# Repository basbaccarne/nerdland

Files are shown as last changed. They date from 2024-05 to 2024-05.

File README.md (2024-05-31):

#  ~~Nerdland~~  Nerdlamp
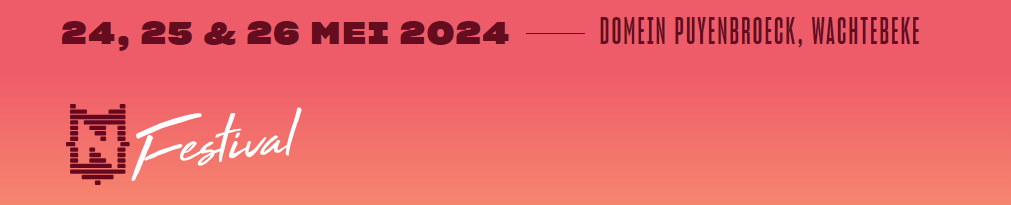
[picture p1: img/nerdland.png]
nerdland

*Made with* ❤ *by Lore Brosens, Bas Baccarne, Yannick Christiaens & Simon De Boever*   

This repo covers the set-up of the [UGent Campus Kortrijk](https://www.ugent.be/campus-kortrijk/) [Nerdland](https://www.nerdlandfestival.be/) installation. This introduces nerds into 4 domains:
- [**Interaction Design**](#interaction-design):   
Visitors can create their own paramertric design with an Arduino-controlled input device
- [**Computational Design**](#computational-design):   
This device feeds a firefly + grasshopper script that generates patterns in a predefined format
- [**Advanced Manufacturing**](#advanced-manufacturing):   
These shapes are exported as dxf files and laser cutted
- [**Design for Assembly**](#design-for-assembly):   
These personalised fragments can be assembled into a night lamp

These domains illustrate some of the key components of the [Ghent University](https://www.ugent.be/) programs [Machine & Production Automation](https://www.ugent.be/campus-kortrijk/nl/opleidingen/mpa) and [Industrial Design Engineering](https://www.ugent.be/campus-kortrijk/nl/opleidingen/industrieel-ontwerpen)

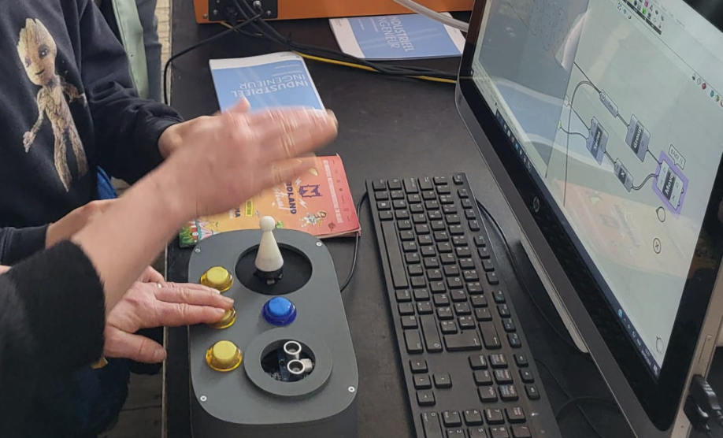
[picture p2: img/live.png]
live


## Interaction Design
### Components
- [Arduino Nano](https://store.arduino.cc/products/arduino-nano)
- [Grove Shield for Arduino Nano](https://wiki.seeedstudio.com/Grove_Shield_for_Arduino_Nano/)
- [Grove Thumbstick](https://wiki.seeedstudio.com/Grove-Thumb_Joystick/)
- [Grove Gesture Sensor 1.0](https://wiki.seeedstudio.com/Grove-Gesture_v1.0/)
- [Grove UltraSonic Ranger](https://wiki.seeedstudio.com/Grove-Ultrasonic_Ranger/)
- [4 arcade buttons](https://www.gotron.be/componenten/schakelmateriaal/schakelaars-en-drukknoppen/arcade-knoppen/lichtgevende-arcade-drukknop-30mm-groen.html)
- [Mini USB Cable](https://www.allekabels.be/usb-mini-kabel/176/4207900/mini-usb-kabel.html?lang=nl-be)
- [Case](https://a360.co/4drFMZX)
- [Joystick](https://a360.co/3WSIDWa)
### Set-up
- Connect the thumbstick to A0
- Connect the gesture sensor to I2C
- Connect the distance sensor to D2
- Connect button 1 to D5
- Connect button 2 to D7
- Connect button 3 to A3
- Connect button 4 to A2 
- Upload the [Arduino code](nerdland.ino)
### Input
- The interface changes the ```thumb stick``` values when the ```first button``` is pressed
- The interface changes the ```gestures``` when the ```second button``` is pressed
- The interfaces changes the ```distance``` when the ```third button``` is pressed
- The interface ```resets``` the values when the ```blue (fourth) button``` is pressed
### Output
- The arduino writes the data to the Serial Port in the folowing format   
  ```x_axis_thumb|y_axis_thumb|x_axis_gesture|y_axis_gesture|distance```

  ![console](img/console.jpg)
      
## Computational Design
- This Serial Data is read by [Firefly](https://www.food4rhino.com/en/app/firefly) and translated into computaional commands in [Grasshopper](https://www.grasshopper3d.com/)
- [This Grasshopper script](grasshopper.gh) shows how the data is processed in Grasshopper
- Parameters: ```size```, ```orientation```, ```pattern```, ```count``` & ```shape```
- The results are 5 copies of personalized segment designs
  
![grasshopper](img/grasshopper.png)   

## Advanced Manufacturing
- The Grasshopper result is baked and exported to a .dxf file
- The dxf file is printed on a laser cutter using [lightburn](https://lightburnsoftware.com/)
- Material: [Akyplen® wit 460 g/m²](https://igepa.nl/06-0007-0007-akyplenr-wit-460-g-m-700-mm-x-1000-mm-500)
- If you want to use the pregenerated design: this is the [file with the base segments](samples/Basis_File_10_sides_en_bodem.dxf) & this is a [pregenerated file with the parts with a pattern](samples/Accent_file_5_sides.dxf)
  
**Curious about the math behind this lamp?**
- The general shape is a [Rhombic triacontahedron](https://en.wikipedia.org/wiki/Rhombic_triacontahedron), with 30 rhombic (diamond-shaped) faces
- From this shape, we remove 20 faces in the middle
- See the video below for a basic visualization
  
https://github.com/basbaccarne/nerdland/assets/7208557/56421a35-1992-435b-bc12-0767cc13a605

## Design for Assembly
- The five segments are printed in the laser cutter
- Visitors get a enveloppe with
  - a preprinted [bottom part](samples/Basis_File_10_sides_en_bodem.dxf)
  - 10 preprinted [segments without a pattern](samples/Basis_File_10_sides_en_bodem.dxf)
  - a small led light that fits in the bottom > [small led tea light](https://www.amazon.com.be/-/en/Afoosoo-Flameless-Battery-Waterproof-Christmas/dp/B0BV1HZ5NH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)
- How to put everything together? Watch this movie
[![assembly](img/assembly.png)](https://www.youtube.com/watch?v=dlgAcVDjcDM)

## End result
![light hanging](img/light_hanging.jpg)
![prototype](img/productv1.png)

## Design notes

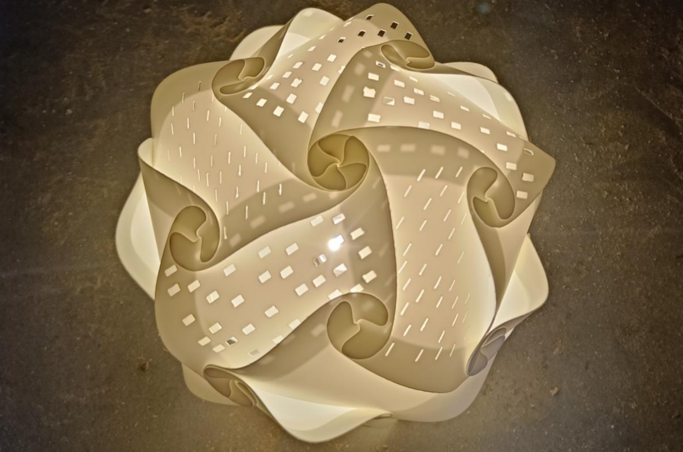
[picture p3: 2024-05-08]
img/productv1.png

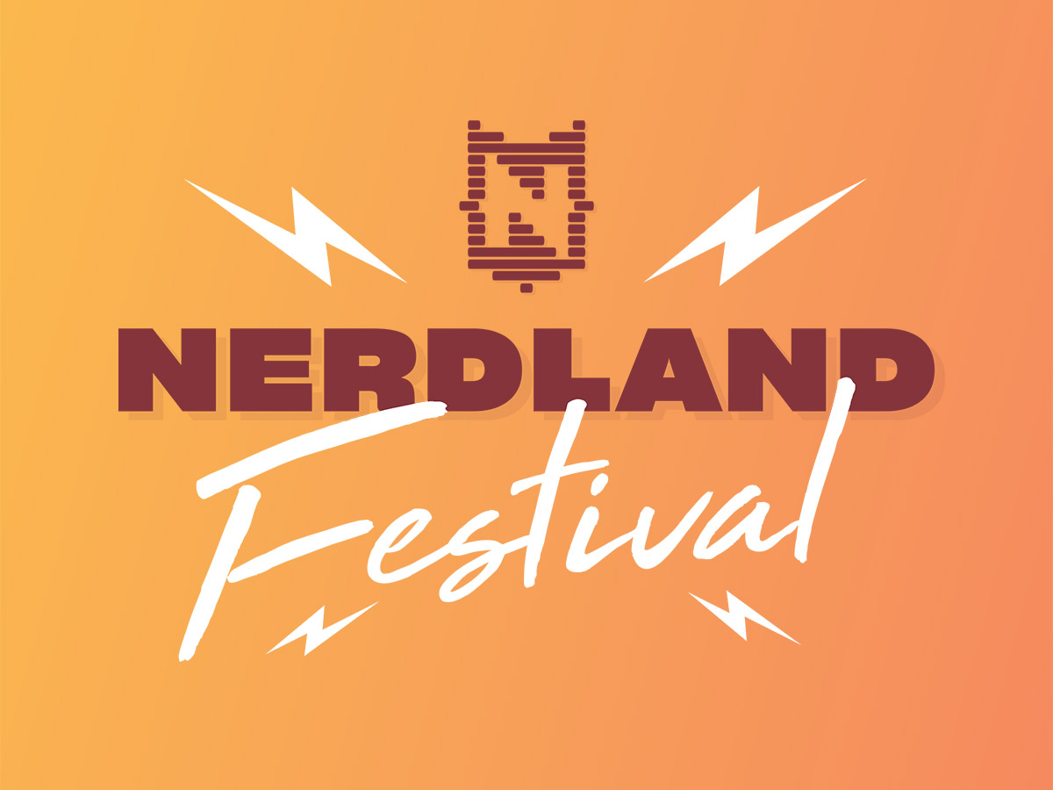
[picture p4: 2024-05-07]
img/nerdland.jpg

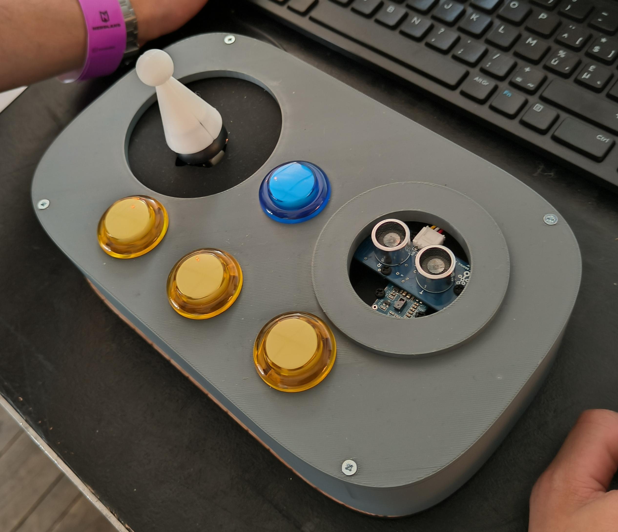
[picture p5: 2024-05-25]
img/console.jpg

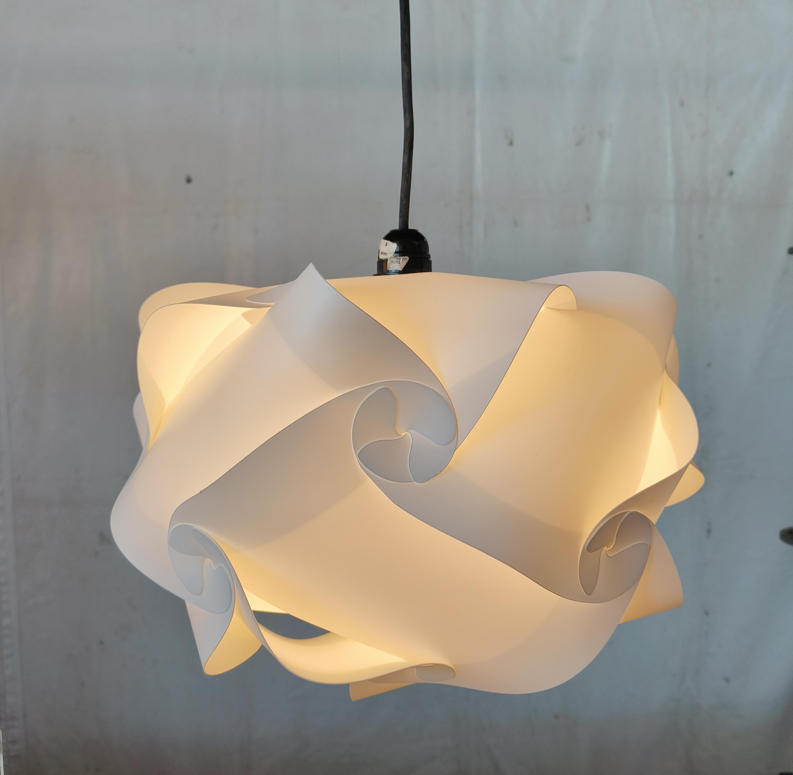
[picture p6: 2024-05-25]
img/light_hanging.jpg

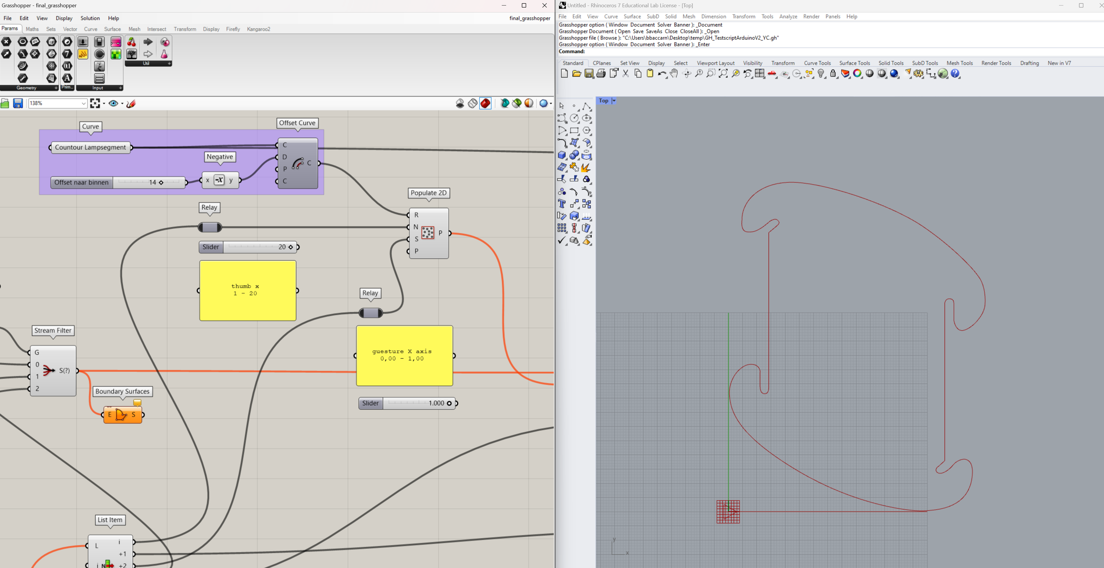
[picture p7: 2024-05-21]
img/grasshopper.png

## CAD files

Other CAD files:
samples/Basis_File_10_sides_en_bodem.dxf
samples/Accent_file_5_sides.dxf

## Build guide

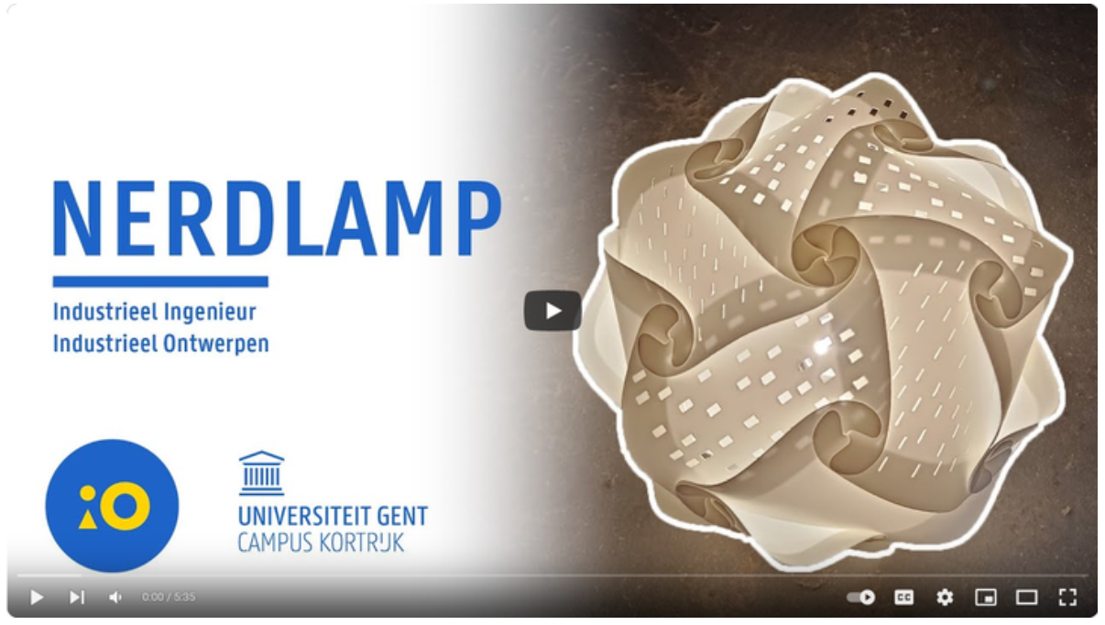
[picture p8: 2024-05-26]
img/assembly.png

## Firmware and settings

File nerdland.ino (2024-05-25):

// libraries
// https://github.com/Seeed-Studio/Grove_Gesture
// https://github.com/Seeed-Studio/Seeed_Arduino_UltrasonicRanger/archive/master.zip

#include <Wire.h>
#include "paj7620.h"
#include "Ultrasonic.h"

// Gesture detection settings (I2C)
#define GES_REACTION_TIME 300
#define GES_ENTRY_TIME 800
#define GES_QUIT_TIME 500

// Timers
unsigned long currentMillis = millis();
unsigned long previousDelay = 0;
unsigned long previousMillis_gesReaction = 0;
unsigned long previousMillis_gesEntryTime = 0;
unsigned long previousMillis_gesQuitReaction = 0;

// ThumbStick Values (A0)
int sensorValue1;
int sensorValue2;

// Set up distance sensor (D2)
Ultrasonic ultrasonic(2);
long RangeInCentimeters;

// Identify buttons
const int button1 = 5;
const int button2 = 7;
byte button3 = A3;
byte button4 = A2;

// Output parameters
int thumb_x = 0;
int thumb_y = 0;
int gest_x = 0;
int gest_y = 0;
float dist = 0.01;

// Default settings (for reset)
int init_thumb_x = 8;
int init_thumb_y = 50;
int init_gest_x = 0;
int init_gest_y = 0;
float init_dist = 1;

void setup()
{
  // Open serial communications
  Serial.begin(9600);

  // Set baseline values
  resetValues();

  // Initialize gesture control
  uint8_t error = 0;
  error = paj7620Init(); // initialize Paj7620 registers
  if (error)
  {
    Serial.print("INIT ERROR,CODE:");
    Serial.println(error);
  }
  else
  {
    Serial.println("INIT OK");
  }

  // Sett-up buttons
  pinMode(button1, INPUT_PULLUP);
  pinMode(button2, INPUT_PULLUP);
  pinMode(button3, INPUT_PULLUP);
  pinMode(button4, INPUT_PULLUP);

}

void resetValues()
{
  thumb_x = init_thumb_x;
  thumb_y = init_thumb_y;
  gest_x = init_gest_x;
  gest_y = init_gest_y;
  dist = init_dist;
}

void getThumb()
{
  // Read the sensor
  sensorValue1 = analogRead(A0);
  sensorValue2 = analogRead(A1);

  // Count the values up or down
  if (sensorValue1 < 500-20)
  {
    if(thumb_x < 20){
      thumb_x++;
    }
  }
  if (sensorValue1 > 500+20)
  {
    if(thumb_x > 1){
      thumb_x--;
    }
  }
  if (sensorValue2 < 500-20)
  {
    if(thumb_y < 90) {
      thumb_y = thumb_y + 10;
    }
    
  }
  if (sensorValue2 > 500+20)
  {
    if(thumb_y > 0){
      thumb_y = thumb_y - 10;
    }
    
  }

  // Debugging prints
  // Serial.println("");
  // Serial.print("Thumb 1: ");
  // Serial.print(sensorValue1);
  // Serial.print(" Thumb 2: ");
  // Serial.println(sensorValue2);
}

void getDist()
{
  // Measure
  RangeInCentimeters = ultrasonic.MeasureInCentimeters();
  // Map
  if (RangeInCentimeters < 80)
  {
    dist = map(RangeInCentimeters, 0, 80, 10, 40);
    dist = dist/10;
  }
  // debugging prints
  // Serial.print(RangeInCentimeters);//0~400cm
  // Serial.println(" cm");
}

void getGesture()
{
  // error prevention
  uint8_t data = 0, data1 = 0, error;
  // read the data
  error = paj7620ReadReg(0x43, 1, &data); // Read Bank_0_Reg_0x43/0x44 for gesture result.
  // interpret the data
  if (!error)
  {
    switch (data) // When different gestures be detected, the variable 'data' will be set to different values by paj7620ReadReg(0x43, 1, &data).
    {
      if (currentMillis - previousMillis_gesEntryTime > GES_REACTION_TIME)
      {
      case GES_RIGHT_FLAG:
        // Serial.println("Up");
        gest_x = random(1, 11);
        break;
      case GES_LEFT_FLAG:
        // Serial.println("Down");
        gest_x = random(1, 11);
        break;
      case GES_UP_FLAG:
        // Serial.println("Left");
        if (gest_y > 0)
        {
          gest_y--;
        }
        break;
      case GES_DOWN_FLAG:
        // Serial.println("Right");
        if (gest_y < 2)
        {
          gest_y++;
        }
        break;
        previousMillis_gesEntryTime = currentMillis;
      }
    }
  }
}

void loop()
{
  // Timer
  currentMillis = millis();

  // Get the data and print the result to firefly each 200 ms
  if (currentMillis - previousDelay > 200)
  {
    if (!digitalRead(button1))
    {
      getThumb();
    }
    if (!digitalRead(button2))
    {
      getGesture();
    }
    if (!digitalRead(button3))
    {
      getDist();
    }
    if (!digitalRead(button4))
    {
      resetValues();
    }

    Serial.print(thumb_x);
    Serial.print("|");
    Serial.print(thumb_y);
    Serial.print("|");
    Serial.print(gest_x);
    Serial.print("|");
    Serial.print(gest_y);
    Serial.print("|");
    Serial.println(dist);
    previousDelay = currentMillis;
  }
}

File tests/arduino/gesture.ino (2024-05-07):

// libraries
#include <Wire.h>
#include "paj7620.h"

// Gesture detection settings
#define GES_REACTION_TIME 300  // You can adjust the reaction time according to the actual circumstance.
#define GES_ENTRY_TIME 800     // When you want to recognize the Forward/Backward gestures, your gestures' reaction time must less than GES_ENTRY_TIME(0.8s).
#define GES_QUIT_TIME 500

// Timers
unsigned long currentMillis = millis();
unsigned long previousMillis_gesReaction = 0;
unsigned long previousMillis_gesEntryTime = 0;
unsigned long previousMillis_gesQuitReaction = 0;


void setup() {
  Serial.begin(9600);

  // initialize gesture control
  uint8_t error = 0;
  error = paj7620Init();  // initialize Paj7620 registers
  if (error) {
    Serial.print("INIT ERROR,CODE:");
    Serial.println(error);
  } else {
    Serial.println("INIT OK");
  }
}

void getGesture() {
  uint8_t data = 0, data1 = 0, error;
  error = paj7620ReadReg(0x43, 1, &data);  // Read Bank_0_Reg_0x43/0x44 for gesture result.
  if (!error) {
    switch (data)  // When different gestures be detected, the variable 'data' will be set to different values by paj7620ReadReg(0x43, 1, &data).
    {
      case GES_RIGHT_FLAG:
        if (currentMillis - previousMillis_gesEntryTime > GES_REACTION_TIME) {
          paj7620ReadReg(0x43, 1, &data);
          if (data == GES_FORWARD_FLAG) {
            Serial.println("Forward");
            delay(GES_QUIT_TIME);
          } else if (data == GES_BACKWARD_FLAG) {
            Serial.println("Backward");
            delay(GES_QUIT_TIME);
          } else {
            Serial.println("Right");
          }
          break;
          case GES_LEFT_FLAG:
            delay(GES_ENTRY_TIME);
            paj7620ReadReg(0x43, 1, &data);
            if (data == GES_FORWARD_FLAG) {
              Serial.println("Forward");
              delay(GES_QUIT_TIME);
            } else if (data == GES_BACKWARD_FLAG) {
              Serial.println("Backward");
              delay(GES_QUIT_TIME);
            } else {
              Serial.println("Left");
            }
            break;
            previousMillis_gesEntryTime = currentMillis;
        }
        // delay(GES_ENTRY_TIME);

      case GES_UP_FLAG:
        delay(GES_ENTRY_TIME);
        paj7620ReadReg(0x43, 1, &data);
        if (data == GES_FORWARD_FLAG) {
          Serial.println("Forward");
          delay(GES_QUIT_TIME);
        } else if (data == GES_BACKWARD_FLAG) {
          Serial.println("Backward");
          delay(GES_QUIT_TIME);
        } else {
          Serial.println("Up");
        }
        break;
      case GES_DOWN_FLAG:
        delay(GES_ENTRY_TIME);
        paj7620ReadReg(0x43, 1, &data);
        if (data == GES_FORWARD_FLAG) {
          Serial.println("Forward");
          delay(GES_QUIT_TIME);
        } else if (data == GES_BACKWARD_FLAG) {
          Serial.println("Backward");
          delay(GES_QUIT_TIME);
        } else {
          Serial.println("Down");
        }
        break;
    }
  }
  delay(100);
}

void loop() {
  // General clock
  currentMillis = millis();
  // Get Gesture
  getGesture();
}

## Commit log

2024-05-08 limit y_axis_gesture from 0 to 2
2024-05-08 Limit y-axis gesture range to 0-2
2024-05-15 button function (only change when button is pressed)
2024-05-22 Update README.md
    De link naar de meest recente versie van de Joystick.
    Geprint met slechts 7% infill 0,2mm layer height.
    Threaded inserts M3
